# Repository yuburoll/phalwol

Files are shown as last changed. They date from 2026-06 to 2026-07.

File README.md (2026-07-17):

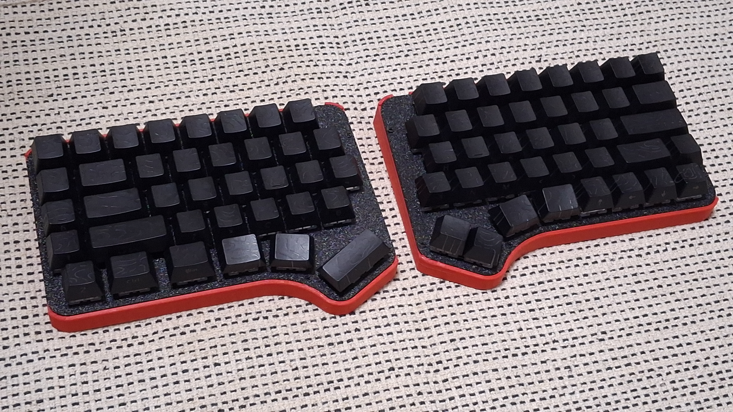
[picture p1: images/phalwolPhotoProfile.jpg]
phalwol


# phalwol
Row staggered 60% keyboard with reversible PCB, inspired by [Hatsukey70](https://scrapbox.io/Hatsukey/)

Hatsuki means August in Japanese, and phalwol means August in Korean. This keyboard layout is an hommage to Hatsukey70, so I want to credit the original design by name.

This keyboard has additional Y/H/B keys which positioned between keyboards, and auxilary row at left outside. You may put the keycaps from numpad.

This keyboard has hotswap-only PCB.

phalwol can change layout to followings:

- Split left shift, to ISO shaped one.(2.25u to 1.25u/1u)

- Split right shift, to HHKB inspired shape.(2.75u to 1.75u/1u)

- Split outside thumb keys(2u to 1u/1u)

- Split backspace(2u to 1u/1u)

- Can use stepped caps lock

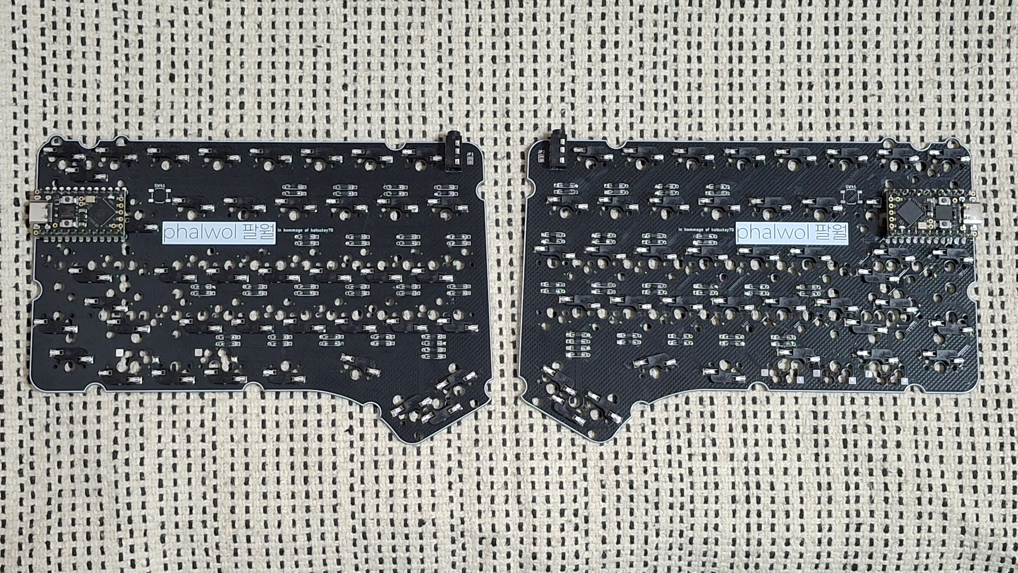
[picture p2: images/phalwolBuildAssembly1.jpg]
phalwolBuildAssembly1


## Preparation

- 2x pro micro form factor dev board

- 2x phalwol PCB Boards, provided from the repo

- 1x printed case sets, 2 parts total, provided from the repo (for thicker case, use "buffed")

- 1x 1.5-1.6T keyboard plate sets, 2 parts total, provided from the repo

- 80x diodes, normally 1N4148

- 84x Kailh hotswap sockets (or compatibles)

- 16x M2x6 screws, flathead

- 2x PJ320A 1/8(3.5mm) TRRS connector (MJ-4PP-9 in other name)

- 2x 4x4x1.5mm surface mount tact switches (optional, for dev boards without reset button)

- 1x 1/8(3.5mm) TRRS cable

- 1-6x PCB Mounted 2u Keyboard Stabilizers, normally 6

- 73-78x MX Keyswitches, normally 73

- 8x 10mm bumpon stickers

- A set of Keycaps, Full-size layout, ANSI preferred.

## Differences between case variations

|Original|Buffed|Frame|
|:---:|:---:|:---:|
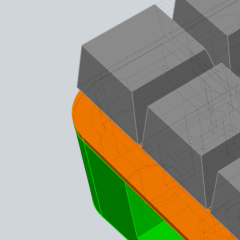
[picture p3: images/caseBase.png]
Base
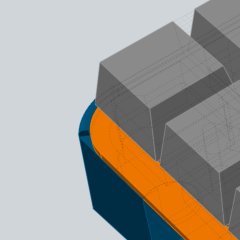
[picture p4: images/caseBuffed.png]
Buff
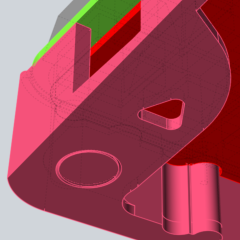
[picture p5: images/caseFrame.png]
Frame
||||

(Frame case are lightest option for 3d print, but it is very brittle)

## Build Guides and Miscellaneous

[phalwol Build Guide](docs/buildGuide.md)

there's some notices before the build:

- You may solder all hotswaps before soldering the dev board.

- Assemble dev board with 2.5mm height pin headers on back side, assume that components side are faced up.

- Jump every jumpers on front side.

[Additional Tenting Stand](https://github.com/yuburoll/yubuGadgets/tree/main/phalilwolTentingStand)

Also take a look at the sibling, [ilwol](https://github.com/yuburoll/ilwol).

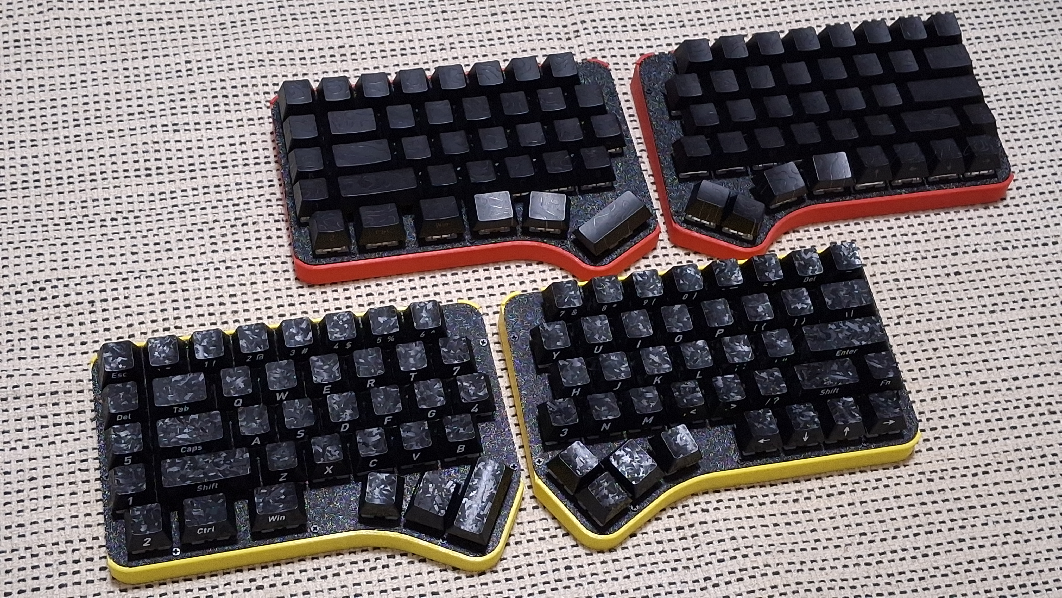
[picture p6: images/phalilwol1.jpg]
phalilwol


## Licenses

All codes are in MIT License.

Markdown documents and photos in docs/images folder are copyrighted, all rights reserved.

The case and layout design of Phalwol is licensed under CC BY-NC-SA 4.0 (Attribution-NonCommercial-ShareAlike) by default, with an additional limited permission for commercial use under the following conditions:

- You are an individual, not acting on behalf of any company or organization.
  
- Your revenue from a single batch of sales does not exceed $2,000.
  
- Your sales are occasional and limited in scope, not ongoing or continuous.

If you want to ask any, please contact the authors.

- me: yuburoll@gmail.com

- Murasaki, the author of original layout Hatsukey70: https://scrapbox.io/Hatsukey/%E4%BD%9C%E8%80%85%E9%80%A3%E7%B5%A1%E5%85%88

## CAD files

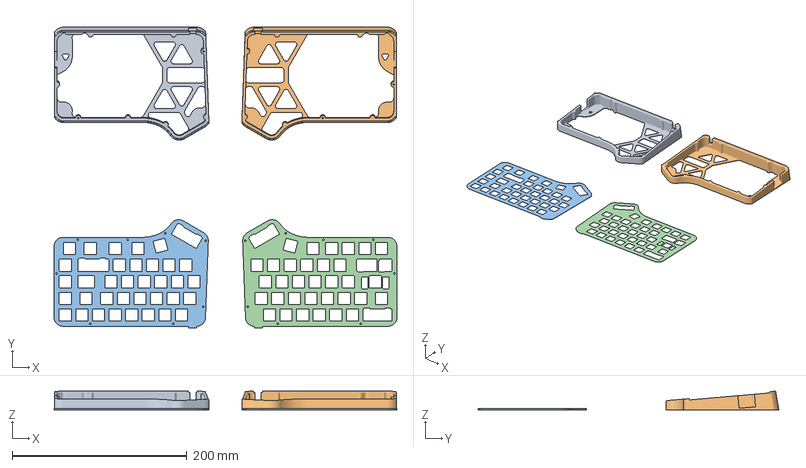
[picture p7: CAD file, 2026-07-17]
case/3mf/phalwolCaseFrame.3mf
392.7 x 344.4 x 21.5 mm
phalwolCaseFrameBridgedL.stl x 2
phalwolPlateBuffedL.stl
phalwolPlateBuffedR.stl

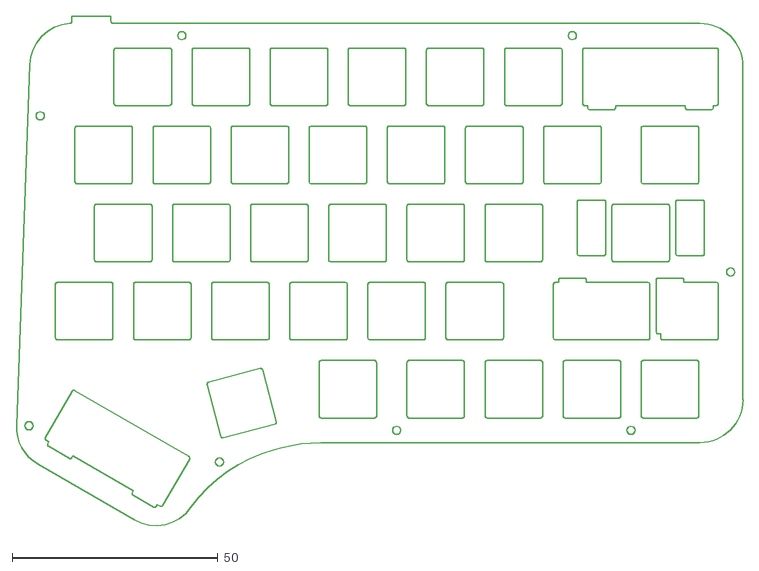
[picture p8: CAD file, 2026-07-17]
case/plateDXF/phalwolPlateBuffedR.dxf
176.8 x 125.2

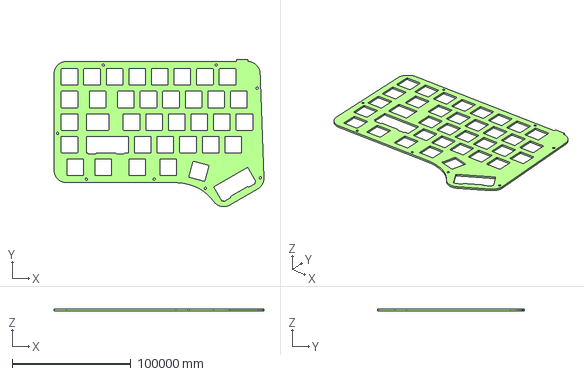
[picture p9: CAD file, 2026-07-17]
case/step/phalwolPlateBuffedL.stp
176699.3 x 123885.5 x 1500.0 mm

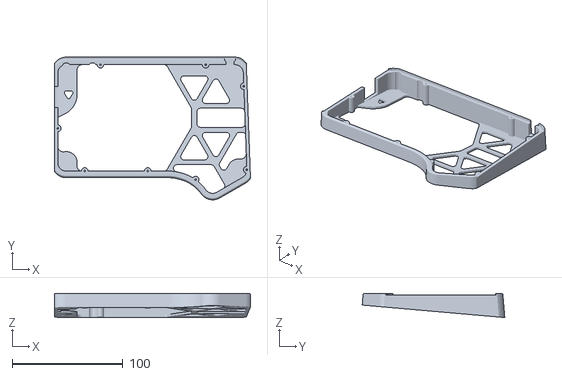
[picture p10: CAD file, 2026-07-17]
case/stl/phalwolCaseFrameBridgedL.stl
177.0 x 128.8 x 21.8

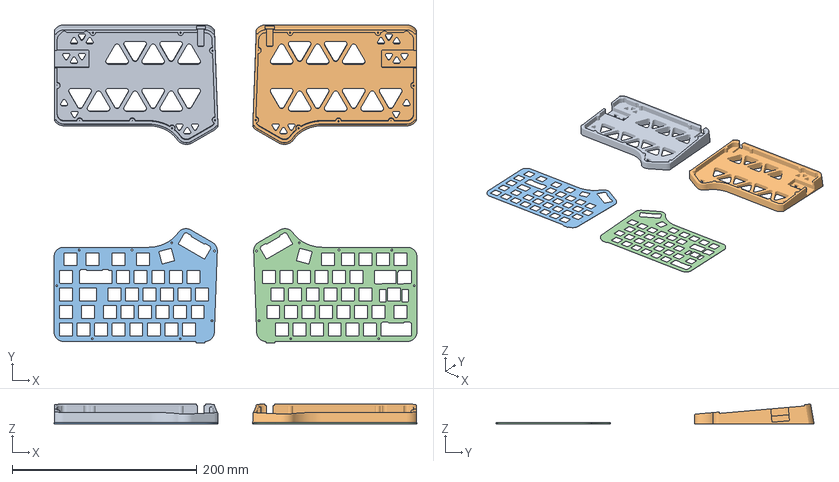
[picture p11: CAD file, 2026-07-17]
case/3mf/phalwolCaseBuffed.3mf
392.7 x 344.4 x 21.5 mm
phalwolCaseBuffedBridgedL.stl x 2
phalwolPlateBuffedL.stl
phalwolPlateBuffedR.stl

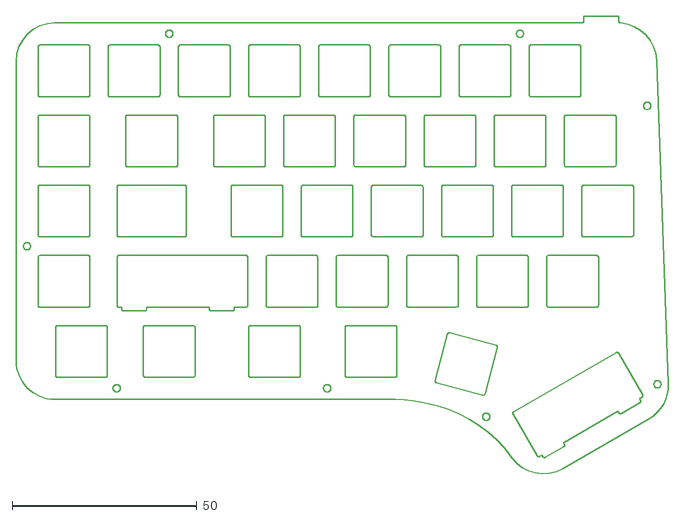
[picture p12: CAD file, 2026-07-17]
case/plateDXF/phalwolPlateBuffedL.dxf
176.8 x 125.2

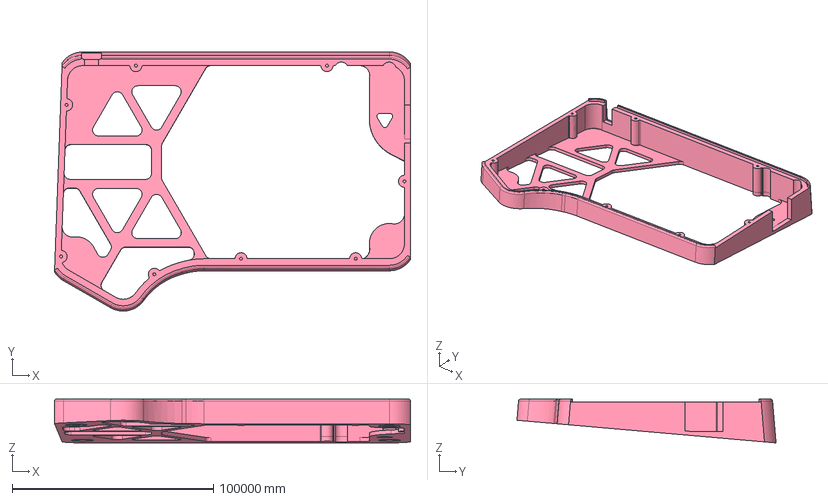
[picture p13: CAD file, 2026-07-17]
case/step/phalwolCaseFrameR.stp
176978.3 x 128826.0 x 21788.3 mm

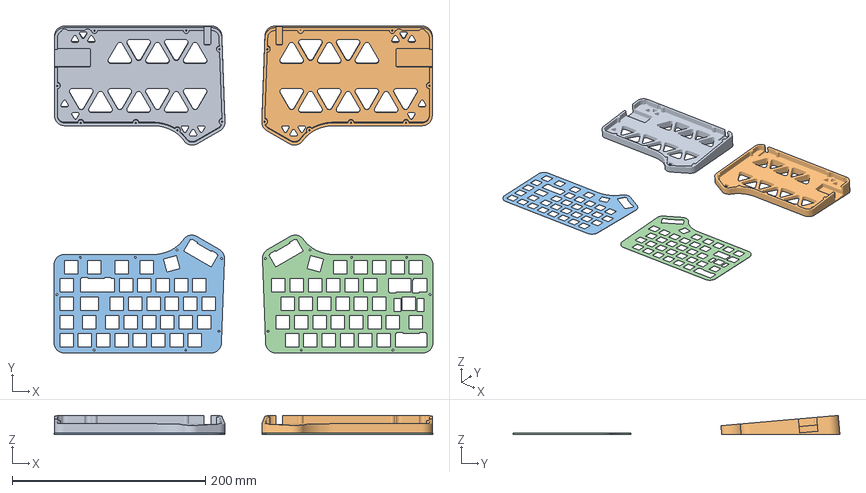
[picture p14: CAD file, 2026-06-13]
case/3mf/phalwolCase.3mf
392.7 x 338.8 x 19.9 mm
phalwolCaseBridgedL.stl x 2
phalwolPlateL.stl
phalwolPlateR.stl

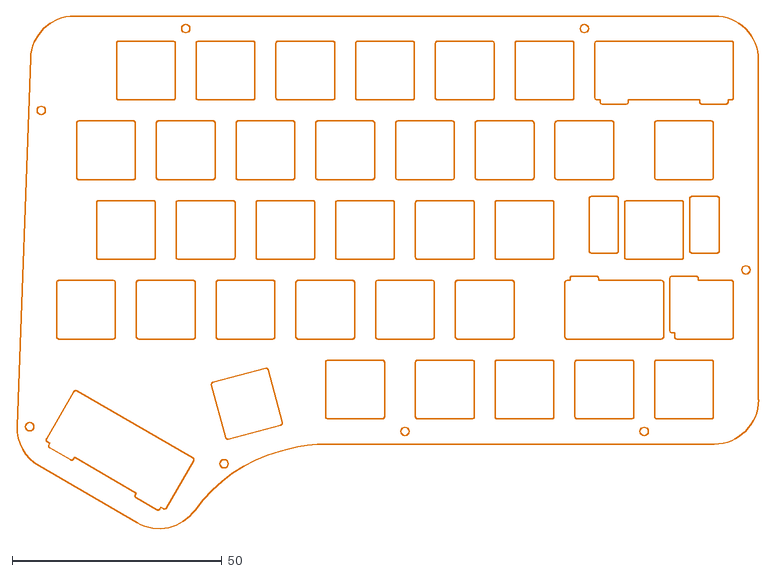
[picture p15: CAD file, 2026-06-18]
case/plateDXF/phalwolPlateR.dxf
176.8 x 123.4

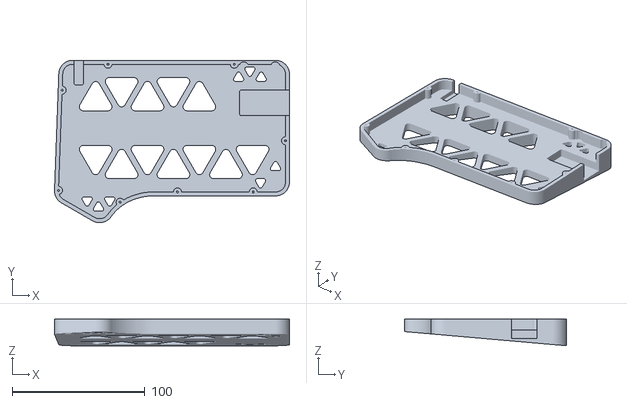
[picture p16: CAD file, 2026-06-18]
case/stl/phalwolCaseBridgedR.stl
176.7 x 122.1 x 20.0

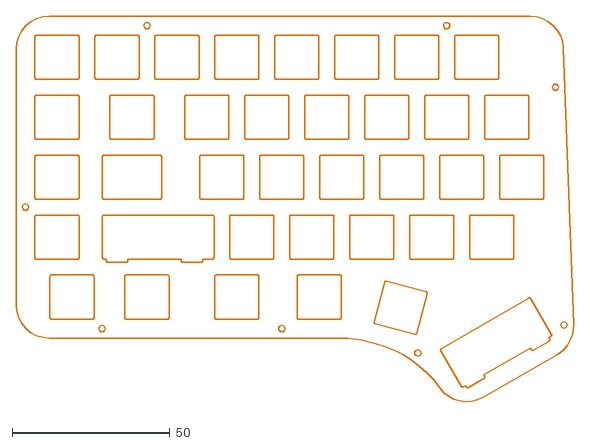
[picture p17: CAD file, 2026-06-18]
case/plateDXF/phalwolPlateL.dxf
176.8 x 123.4

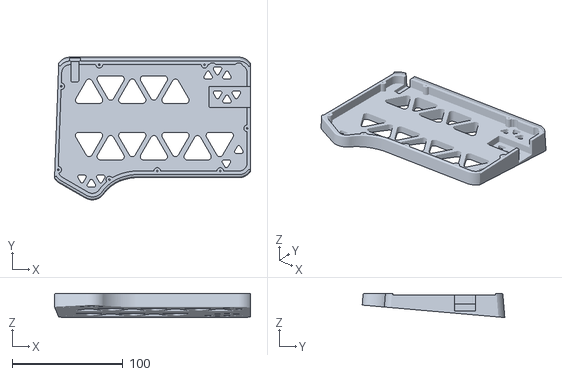
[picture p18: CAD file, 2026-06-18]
case/stl/phalwolCaseBuffedBridgedR.stl
177.0 x 128.8 x 21.8

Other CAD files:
case/stl/phalwolCaseFrameBridgedR.stl
case/step/phalwolPlateBuffedR.stp
case/step/phalwolCaseFrameL.stp
case/step/phalwolPlateR.stp
case/stl/phalwolCaseBridgedL.stl
case/step/phalwolPlateL.stp
case/raw/phalwol.3dm
case/step/phalwolCaseBuffedL.stp
case/step/phalwolCaseBuffedR.stp
case/step/phalwolCaseL.stp
case/step/phalwolCaseR.stp
case/stl/phalwolCaseBuffedBridgedL.stl
case/stl/phalwolCaseBuffedL.stl
case/stl/phalwolCaseBuffedR.stl
case/stl/phalwolCaseFrameL.stl
case/stl/phalwolCaseFrameR.stl
case/stl/phalwolCaseL.stl
case/stl/phalwolCaseR.stl
case/stl/phalwolPlateBuffedL.stl
case/stl/phalwolPlateBuffedR.stl
case/stl/phalwolPlateL.stl
case/stl/phalwolPlateR.stl

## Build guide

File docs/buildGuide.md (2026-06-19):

# Build Guide
this is build guide for phalwol.

the build guide contains photo of prototype version. newest version have following differences:

- the corner screws of outside top are moved 1u inside, so do the PCB design.

- lower pinky modifier keys are not changeable. as black marked in prototype PCB

This documents are translated by generative AI, so there can be some misleading texts.

### Additional Resources
[**Soldering Tips**](solderingTip.md)

# PCB Preparation
Prepare two PCBs for the phalwol. Since these are reversible PCBs, be careful to place components on different sides for each board.

The side where components will be placed is treated as the back, and the side without components is treated as the front. **All components go on back side only, so please be careful when soldering.**

# Soldering the Diodes
Solder the diodes. The photos show SMD diodes being used, but THT diodes can also be used.

In the photo, the hot-swap sockets are soldered first, but I recommend soldering the diodes first.

When using SMD diodes, first apply a solder blob to one side of the pad with a soldering iron, as shown in the following photos.

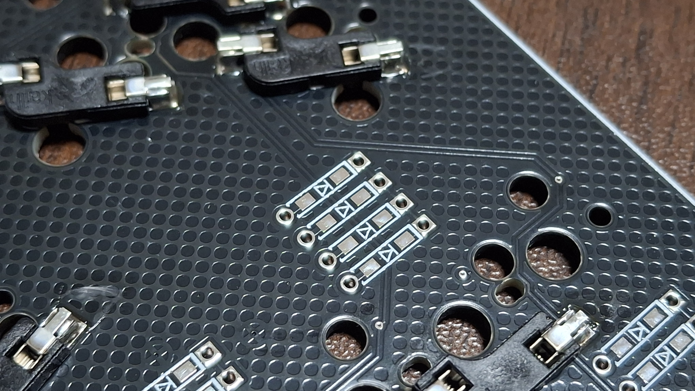
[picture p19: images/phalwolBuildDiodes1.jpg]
phalwolBuildDiodes1

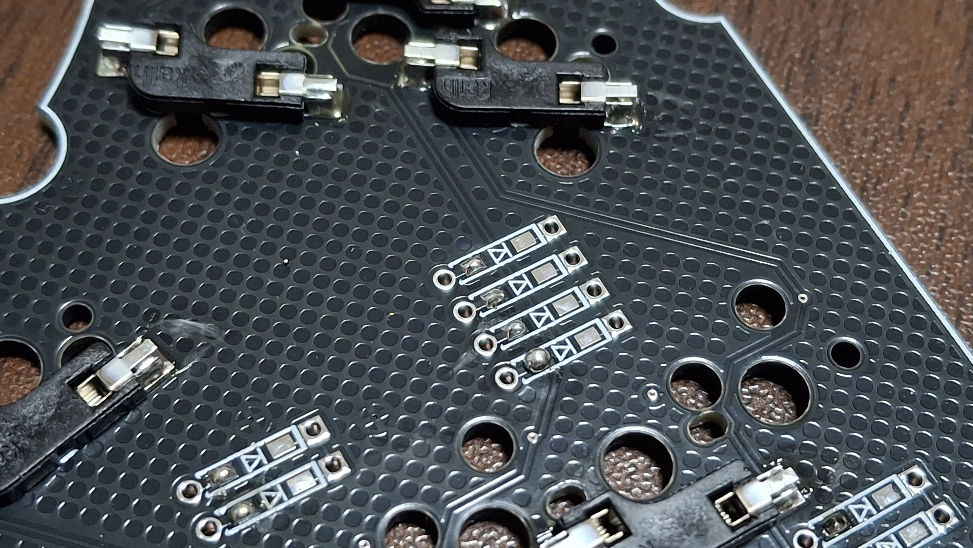
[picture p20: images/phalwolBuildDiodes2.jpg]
phalwolBuildDiode2


Reheat the solder blob with the iron to melt it, align the diode in the correct orientation and place it in position, then remove the iron.

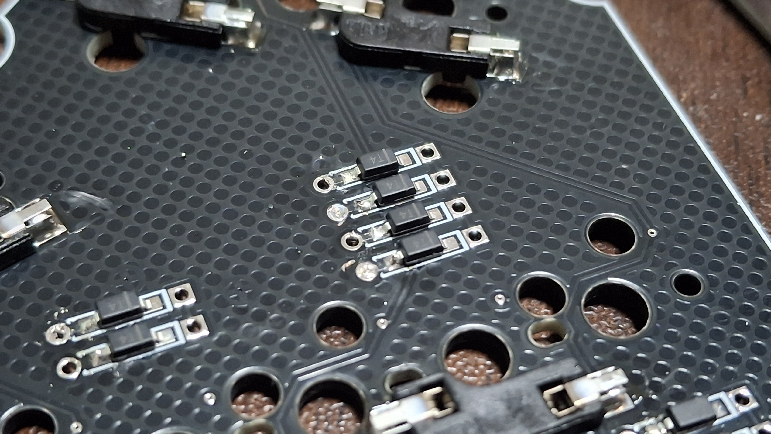
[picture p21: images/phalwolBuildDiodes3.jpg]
phalwolBuildDiode3


Once it is seated properly, solder the opposite leg.

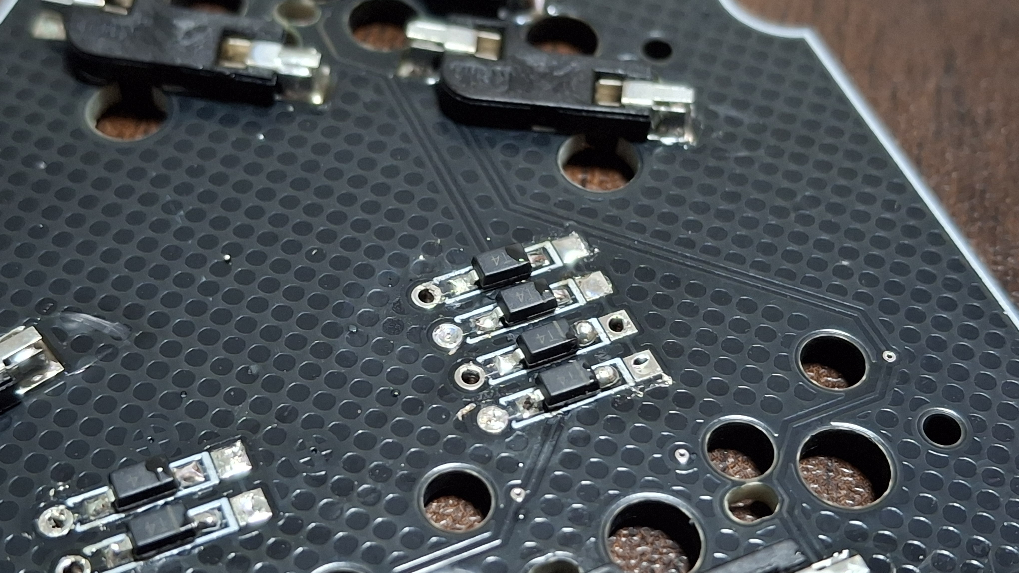
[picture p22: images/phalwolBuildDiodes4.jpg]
phalwolBuildDiode4


# Soldering the Hot-swap Sockets
Solder the hot-swap sockets. The process is largely the same as soldering the diodes and LEDs.

As before, apply a solder blob to one side of the pad, reheat the blob to melt it, place the component and hold it in position, remove the iron, then solder the opposite leg.

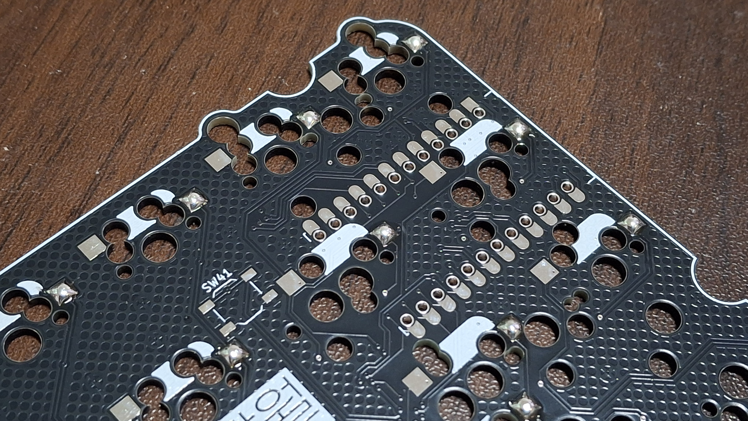
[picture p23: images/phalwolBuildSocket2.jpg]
phalwolBuildSocket2

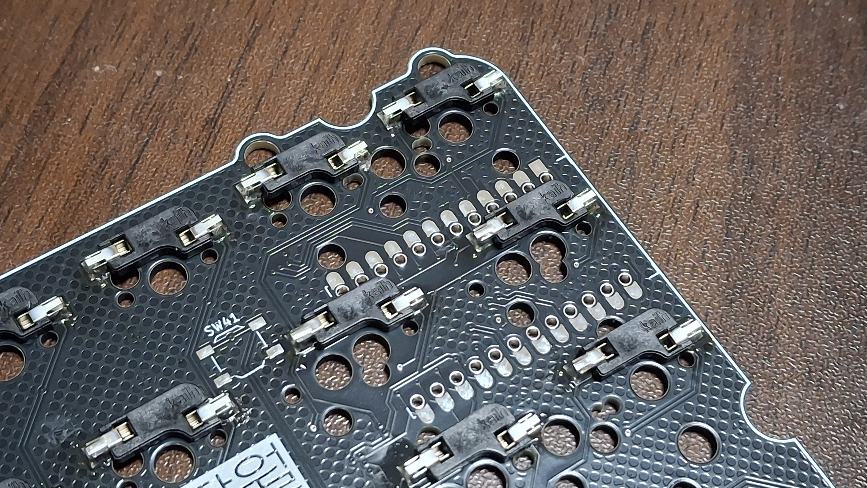
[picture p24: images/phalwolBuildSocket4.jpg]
phalwolBuildSocket4


# Soldering the TRRS Jack and the Jumper
Refer to the following photos to identify where the TRRS jack will be placed. The jack will be placed on back side, so you may solder that on front side.

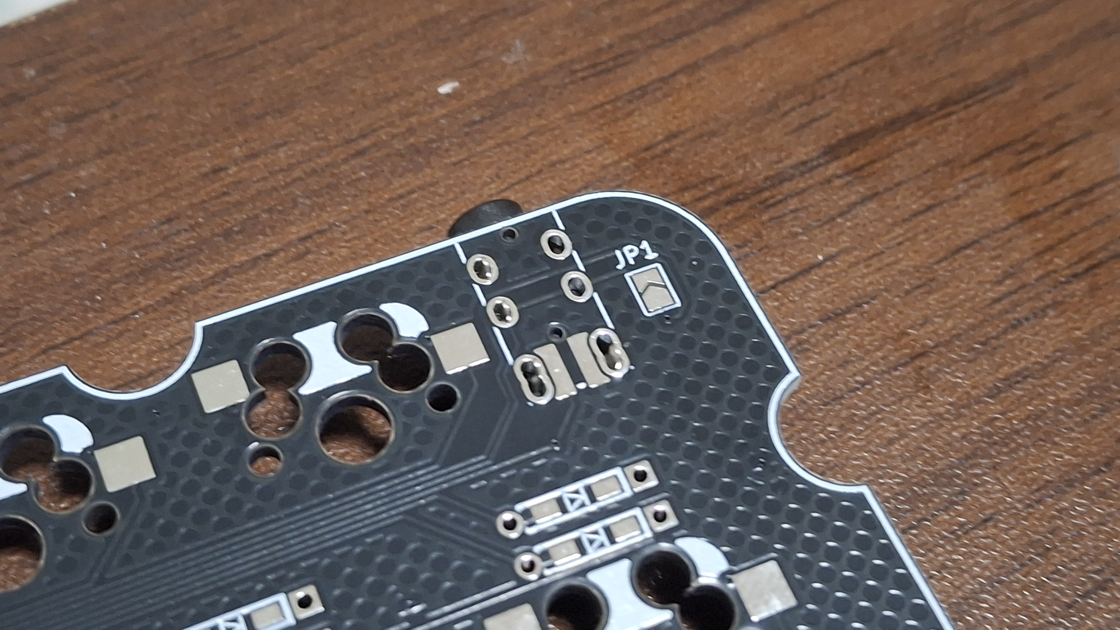
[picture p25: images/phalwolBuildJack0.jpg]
phalwolBuildJack0


Solder the TRRS jack. When soldering the Tip and Sleeve pins, also bridge them to the adjacent pads as shown in the photo.

And, On the front side seen when soldering the jack, bridge the jumpers located aside. Apply enough solder so that a blob forms on top.

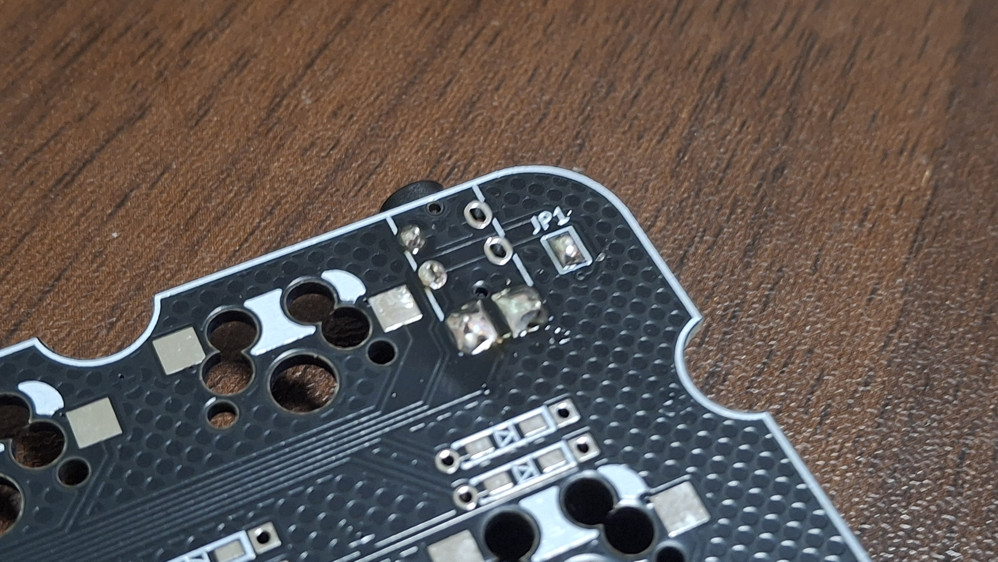
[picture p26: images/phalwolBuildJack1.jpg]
phalwolBuildJack1


# Soldering the Dev Board
First, check the header pins on the provided Pro Micro dev board. The outermost row of header pins past 5V is not needed, so trim them off.

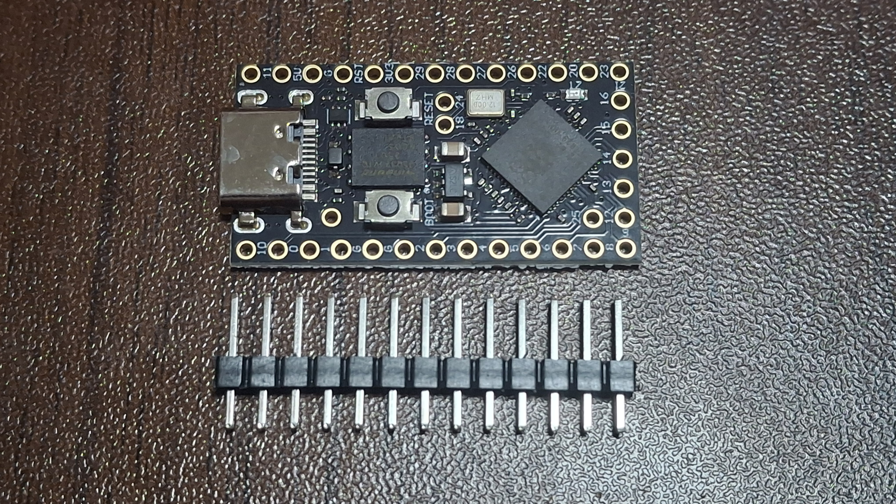
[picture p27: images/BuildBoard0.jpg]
BuildBoard0

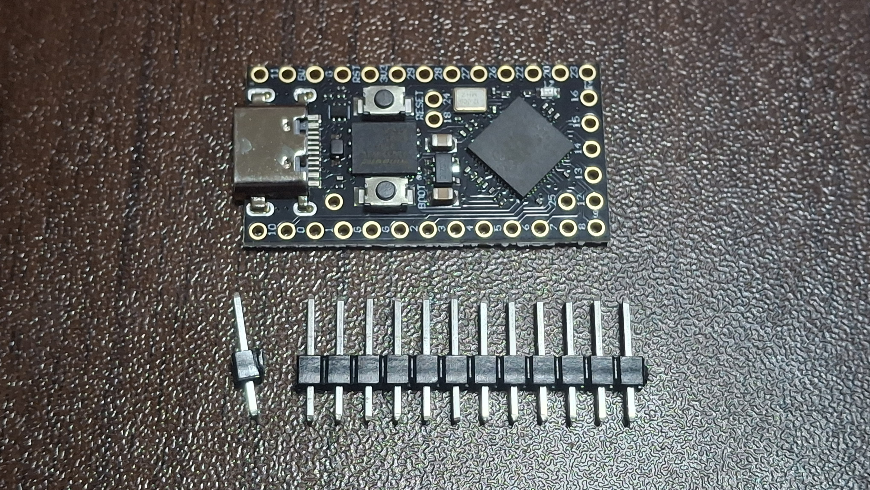
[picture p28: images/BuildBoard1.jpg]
BuildBoard1


Insert the header pins starting from 5V, align them, and solder the dev board. When soldering, make sure the components face upward as shown in the photo.

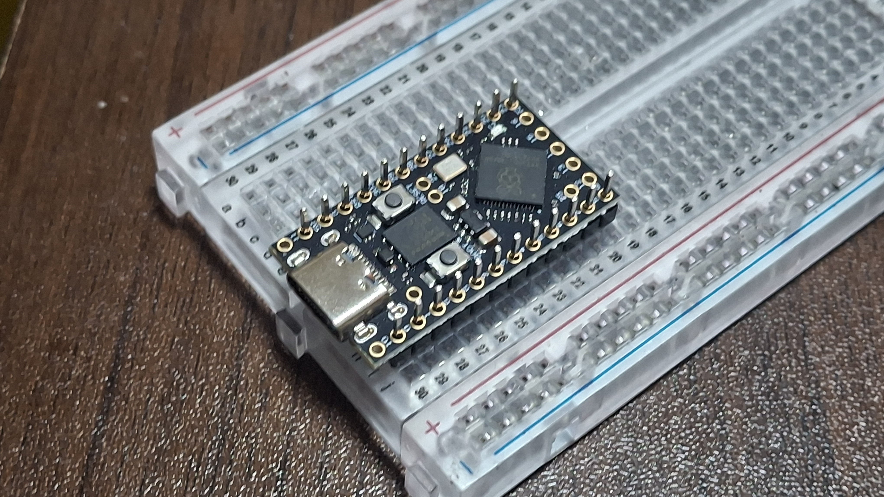
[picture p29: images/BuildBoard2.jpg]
BuildBoard2

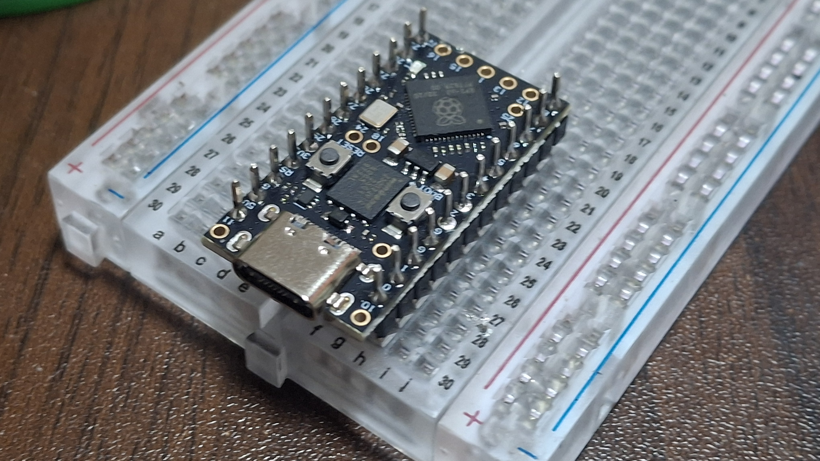
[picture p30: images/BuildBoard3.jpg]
BuildBoard3


Place the dev board with the soldered header pins on top of the already-soldered hot-swap sockets. Press down firmly to ensure a tight fit.

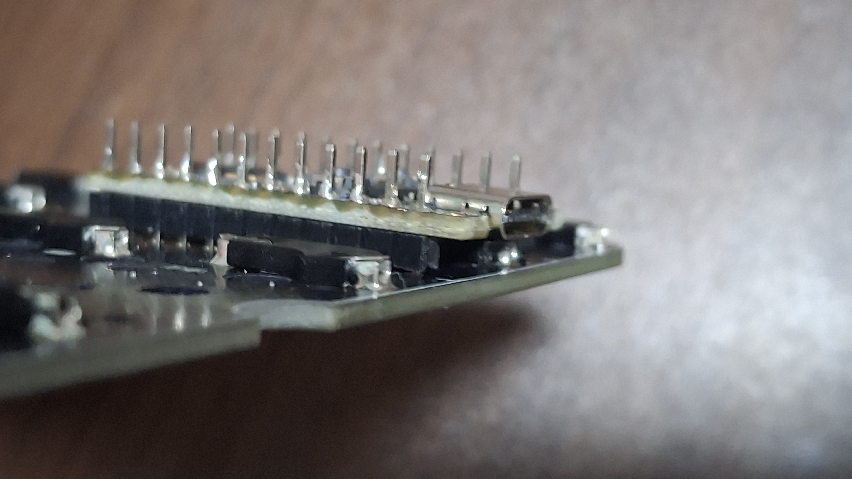
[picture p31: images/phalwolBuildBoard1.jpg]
phalwolBuildBoard1

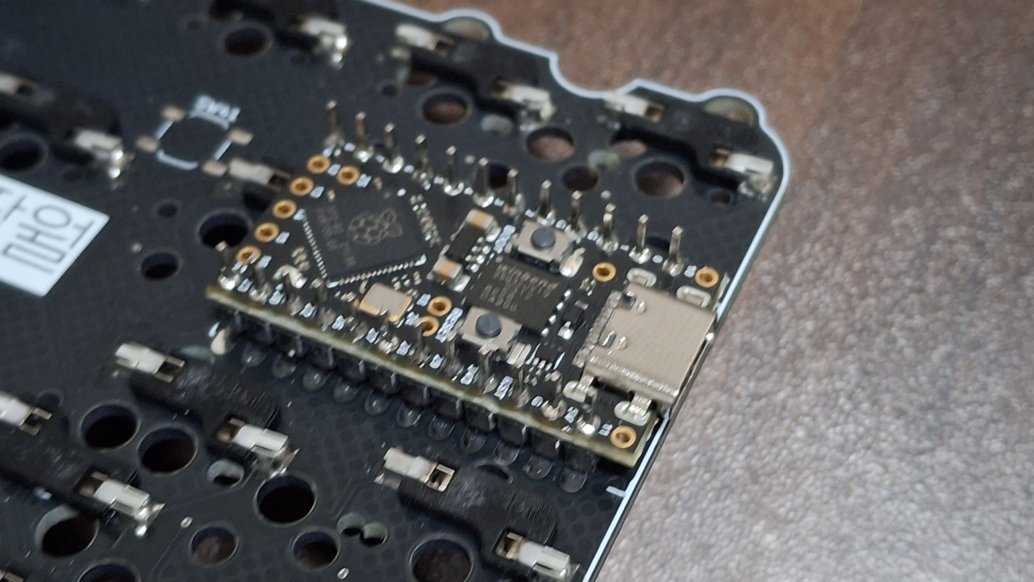
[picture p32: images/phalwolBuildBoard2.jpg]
phalwolBuildBoard2

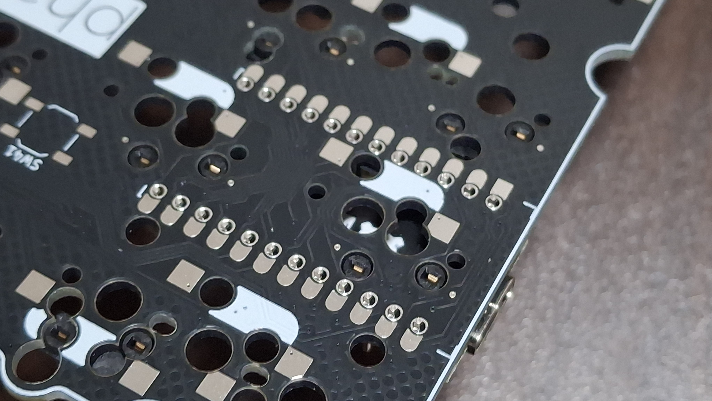
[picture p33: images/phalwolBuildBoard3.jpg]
phalwolBuildBoard3


Just like when soldering the TRRS jack pins, bridge the header pins to the adjacent pads as if soldering jumpers. Since a large amount of solder is used, there is a risk of bridging with flux, so be sure to clean the area with alcohol after soldering.

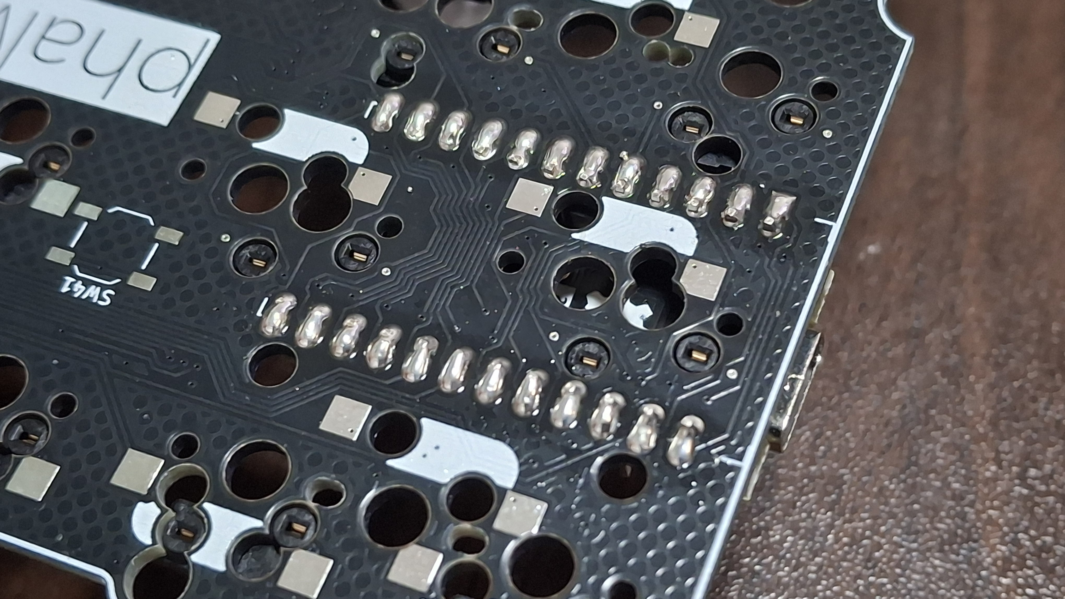
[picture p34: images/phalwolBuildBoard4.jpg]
phalwolBuildBoard4


# Check PCB and flash firmware before Assembly
The finished PCBs look like following images.

phalwolBuildAssembly1
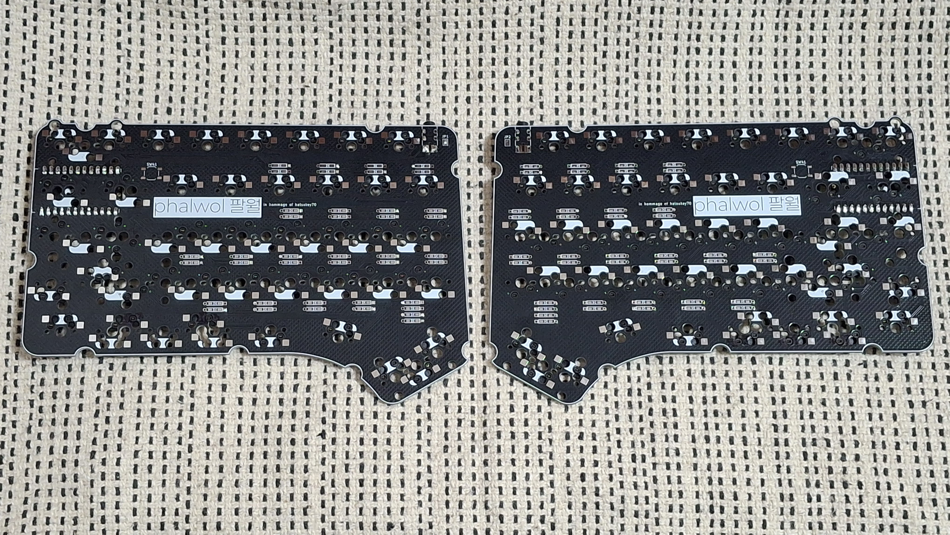
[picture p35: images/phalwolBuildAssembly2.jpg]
phalwolBuildAssembly2


If you're a keyboard enthusiast, I'd recommend installing stabilizers at keycap positions 2u or larger, as shown in the following photo.

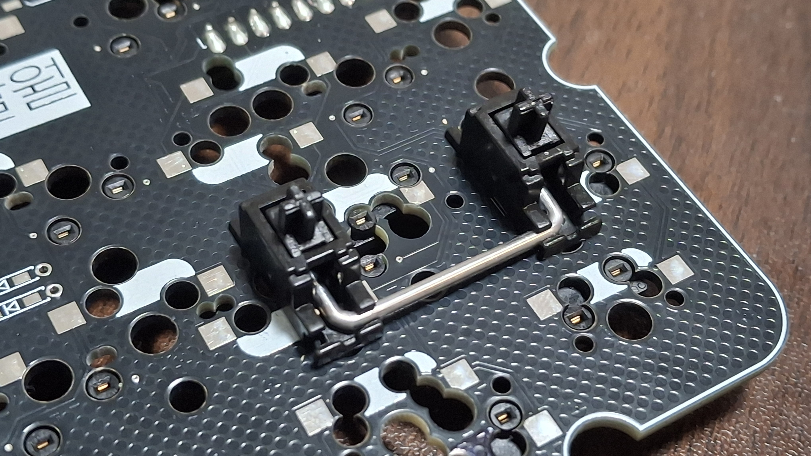
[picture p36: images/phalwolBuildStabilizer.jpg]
phalwolBuildStabilizer


Also, please flash the firmware before assembling the case.

For the RP2040 promicro, hold down the Boot button on the development board while connecting the USB, then drop the .uf2 file onto the removable disk that appears.

For the ATmega32U4 promicro, load the firmware .hex in your flashing tool (e.g., QMK Toolbox). Then, with the USB connected, briefly short RST and GND with a conductor, or solder a 4x4x1.5mm tactile switch to those pads and press it. The Caterina bootloader will activate and the tool will flash the firmware.

# Assembly
First, assemble plate and switches together with proper direction, and assemble PCB on it.

You can fasten all the switches to the plate first and then join it to the PCB, but I also recommend the method shown in the photo: attach the switches to the four corners first, place the PCB, and then assemble the remaining switches one by one.

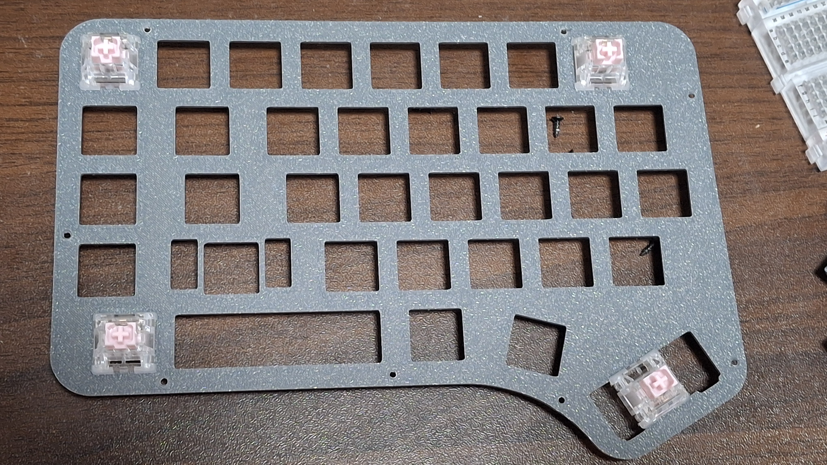
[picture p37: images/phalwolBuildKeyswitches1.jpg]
phalwolBuildKeyswitches1

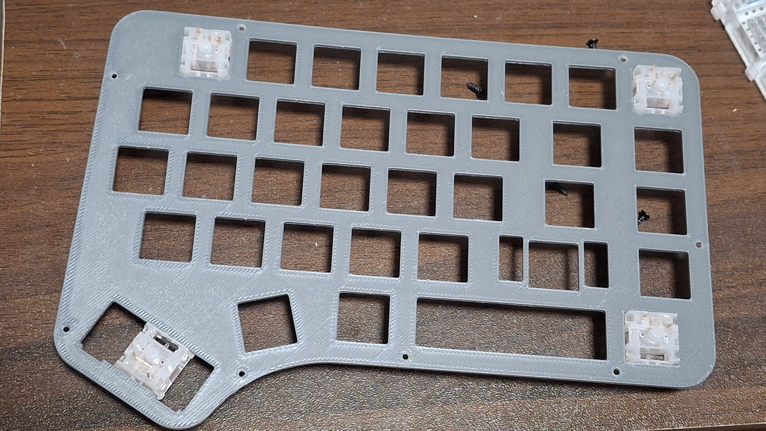
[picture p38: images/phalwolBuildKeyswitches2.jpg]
phalwolBuildKeyswitches2

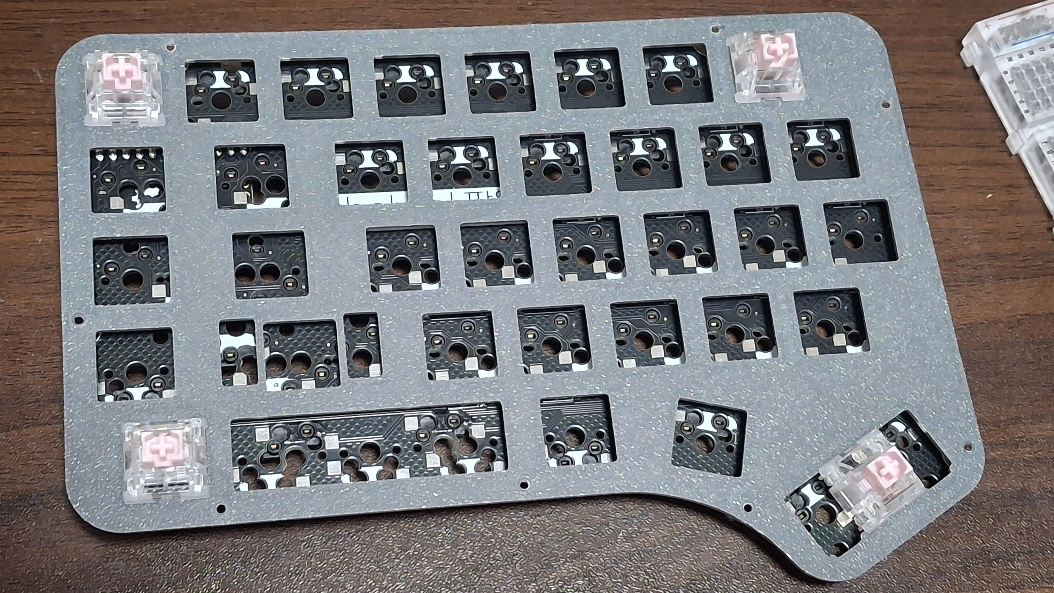
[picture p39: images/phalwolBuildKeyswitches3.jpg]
phalwolBuildKeyswitches3

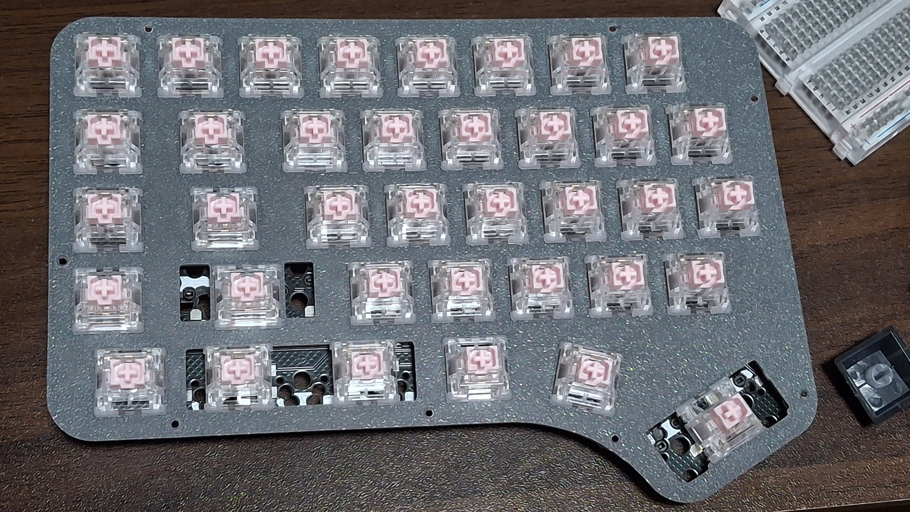
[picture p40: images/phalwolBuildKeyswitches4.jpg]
phalwolBuildKeyswitches4


Place the plate assembly over the case and fasten it with screws at eight points per side to complete the build. also, you may add four bumpons on the bottom of the case.

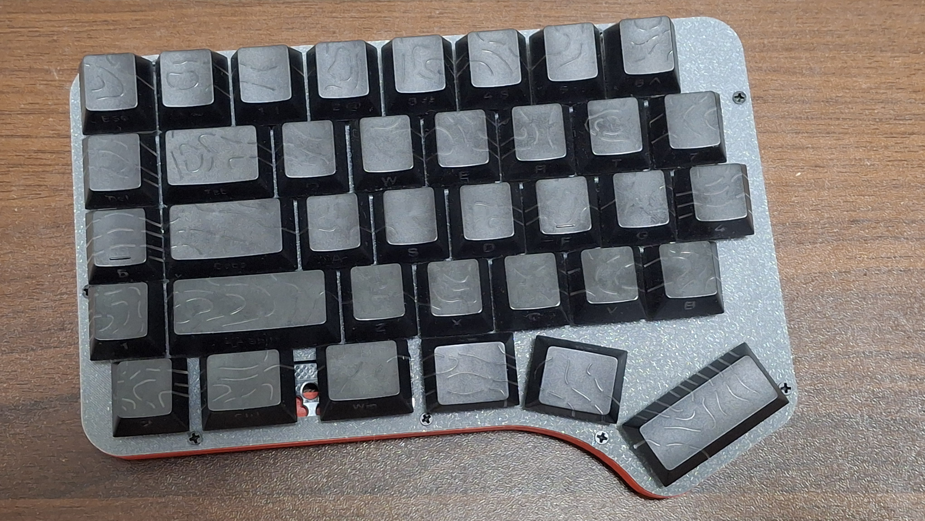
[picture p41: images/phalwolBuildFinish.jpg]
phalwolBuildFinish


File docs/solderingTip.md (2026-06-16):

# Soldering Tips

A collection of soldering advice and tips.

This documents are translated by generative AI, so there can be some misleading texts.

## Supplies

- Soldering iron & stand: A chisel tip is the most convenient to work with. I recommend getting one that can maintain a temperature of at least 400–500°C.

- Solder: Choose between leaded and lead-free solder. Leaded solder is less stressful to work with, but it is not good for your health.

- Solder paste (flux): **The god of soldering.** If your solder joints are not turning out well, frequently wipe and coat the iron tip with paste flux.

- Damp sponge/paper towel, or a tip cleaner (brass wool): Used to wipe residual solder off the iron tip.

- Solder wick or solder sucker: Used to fix bad solder joints. For beginners, solder wick is recommended.

- Flush cutters: Used to clip the legs of THT diodes after soldering.

## Ventilate Your Workspace

The metal fumes from melting solder are a concern, but they are actually quite minimal. The bigger issue is the smoke from the rosin flux inside the solder burning and melting — it is quite harmful and produces a lot of smoke. It is very bad for your health, so ventilate the area, or if ventilation is not possible, make sure to use an air purifier. Always wear a mask.

## Double-Check Before Soldering Components

It is easier to prevent a bad solder joint than to fix one. To correct a solder joint, apply flux to solder wick and press it against the joint with the iron, or apply a small amount of flux to the iron tip, melt the solder, and simultaneously press a solder sucker against it to absorb the solder.

## Apply Flux If Solder Is Not Sticking

Melt flux onto the iron tip to coat it, or use a flux pen to apply it directly to the PCB pads.

## Touch the Iron First When Starting, Remove It Last When Finishing

Place the iron on the pad first to preheat the PCB and component, then melt the solder onto the joint. When finishing, remove the solder first, then remove the iron last.

## Use Masking Tape to Temporarily Hold Components

For components like sockets, securing them with masking tape before soldering is helpful. This is especially important when you need to flip the board over, as components can be difficult to hold in place.

## Clean the Flux After Soldering

Scrub the remaining flux and any areas prone to short circuits thoroughly using a toothbrush dipped in isopropyl alcohol. You can also spray alcohol on the board, scrub with a toothbrush, and let it dry. Keyboard key inputs may work fine with residual flux, but encoders and analog inputs are more susceptible to issues caused by flux bridging.

## If Something Goes Wrong, Reflow and Clean

Problems can arise from cold joints, insufficient solder, excess solder bridging neighboring pads, or electrical interference from flux residue. In most cases, reflowing the solder joint and cleaning the flux will resolve the issue.

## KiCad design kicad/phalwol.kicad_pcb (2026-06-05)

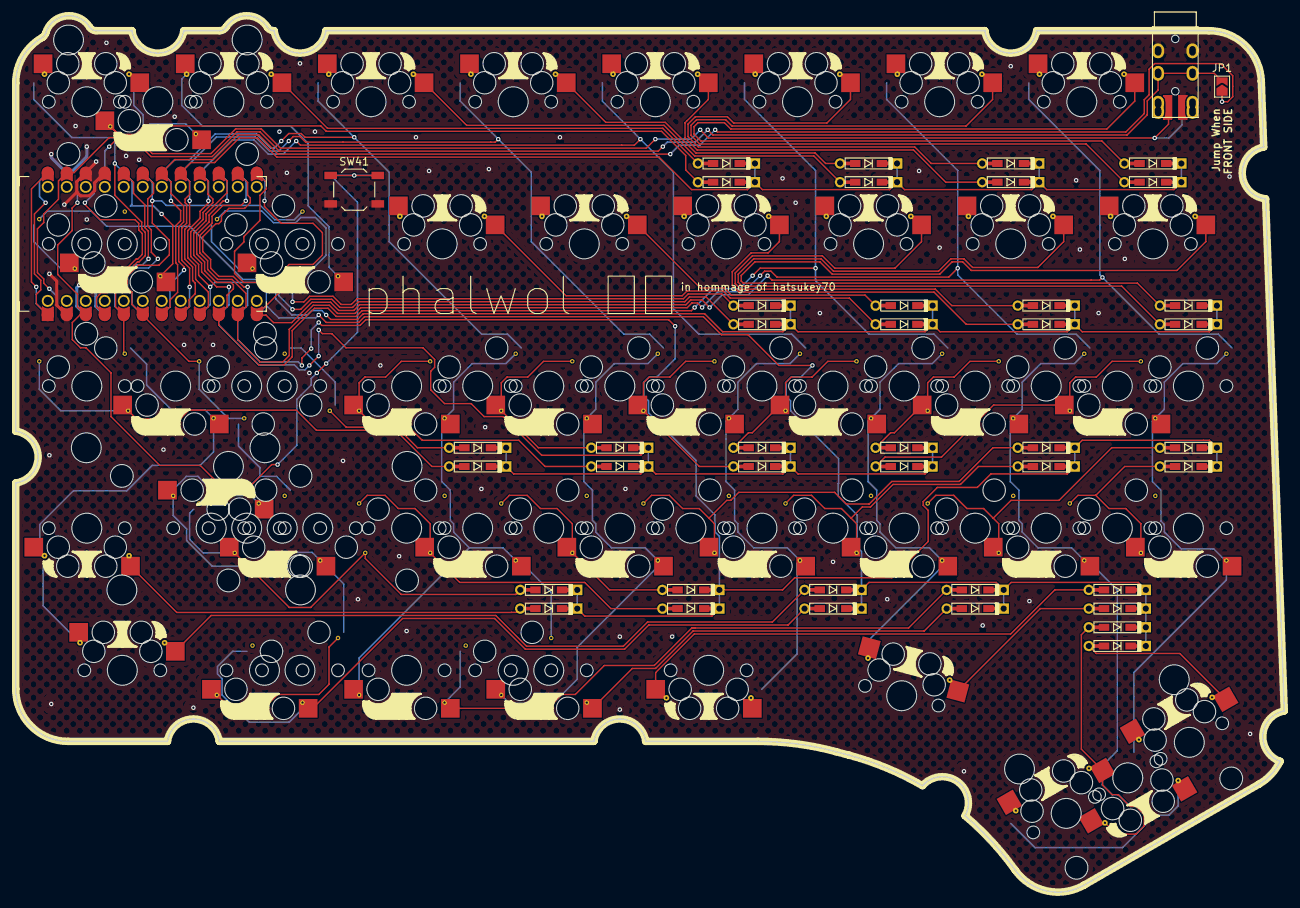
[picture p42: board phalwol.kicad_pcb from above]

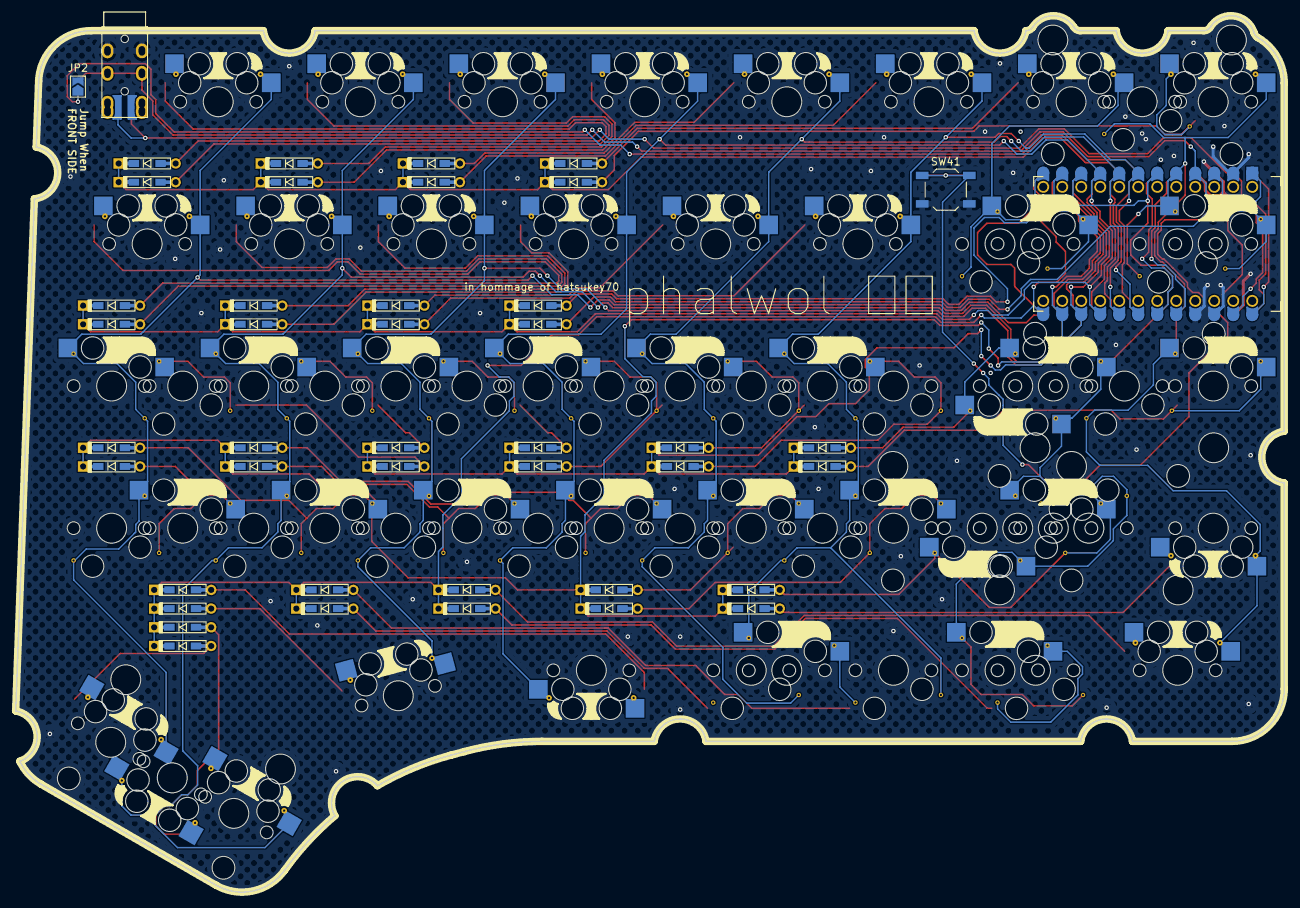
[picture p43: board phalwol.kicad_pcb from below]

Board: 2 copper layers, 169.6 x 117.1 mm, 108 parts (23 on the bottom side), 58 nets.

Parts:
D1, D2, D3, D4, D5, D6, D7, D8, D9, D10, D11, D12, D13, D14, D15, D16, D17, D18, D19, D20, D21, D22, D23, D24, D25, D26, D27, D28, D29, D30, D31, D32, D33, D34, D35, D36, D37, D38, D39, D40: D; Diode_TH_SMD_REVERSIBLE
J1: AudioJack4; TRRS-PJ-320A-ReversiblePad
JP1, JP2: SolderJumper_2_Open; SolderJumper-2_P1.3mm_Open_TrianglePad1.0x1.5mm
SW1, SW9, SW9#2, SW10, SW10#2, SW17, SW17#2, SW18, SW19, SW19#2, SW20, SW20#2, SW21, SW21#2, SW22, SW22#2, SW23, SW23#2, SW24, SW24#2, SW26, SW26#2, SW26#3, SW26#4, SW27, SW27#2, SW28, SW28#2, SW29, SW29#2, SW30, SW30#2, SW31, SW31#2, SW32, SW32#2, SW34, SW34#2, SW35, SW35#2, SW36: SW_Push; MX_HotswapOneside_Via_Guided
SW1#2, SW2, SW3, SW4, SW5, SW6, SW7, SW8, SW11, SW12, SW13, SW14, SW15, SW16, SW25, SW33, SW37, SW38, SW39, SW39#2, SW40: SW_Push; MX_Hotswap_FootprintPropertyFix_Guided
SW41, SW41#2: SW_Push; SW_SPST_TL3342
U1: ProMicro; ProMicro_ReveribleThru_ComponentUp_OuterPad

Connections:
COL1: SW1.1, SW1#2.1, SW9.1, SW9#2.1, SW17.1, SW17#2.1, SW25.1, SW33.1, U1.20 (F4/A3)
COL2: SW2.1, SW10.1, SW10#2.1, SW18.1, SW26.1, SW26#2.1, SW26#3.1, SW26#4.1, SW34.2, SW34#2.1, U1.19 (F5/A2)
COL3: SW3.1, SW11.1, SW19.1, SW19#2.1, SW27.1, SW27#2.1, SW35.2, SW35#2.1, U1.18 (F6/A1)
COL4: SW4.1, SW12.1, SW20.1, SW20#2.1, SW28.1, SW28#2.1, SW36.2, U1.17 (F7/A0)
COL5: SW5.1, SW13.1, SW21.1, SW21#2.1, SW29.1, SW29#2.1, SW37.1, U1.16 (B1/15)
COL6: SW6.1, SW14.1, SW22.1, SW22#2.1, SW30.1, SW30#2.1, SW38.1, U1.15 (B3/14)
COL7: SW7.1, SW15.1, SW23.1, SW23#2.1, SW31.1, SW31#2.1, SW39.1, SW39#2.1, U1.14 (B2/16)
COL8: SW8.1, SW16.1, SW24.1, SW24#2.1, SW32.1, SW32#2.1, SW40.1, U1.13 (B6/10)
GND: J1.R2, J1.S, JP2.2 (B), SW41.2, SW41#2.2, U1.3 (GND), U1.4 (GND), U1.23 (GND)
HAND: JP1.1 (A), JP2.1 (A), U1.7 (4/D4)
unnamed: D1.2 (A), SW1.2, SW1#2.2
unnamed: D2.2 (A), SW2.2
unnamed: D3.2 (A), SW3.2
unnamed: D4.2 (A), SW4.2
unnamed: D5.2 (A), SW5.2
unnamed: D6.2 (A), SW6.2
unnamed: D7.2 (A), SW7.2
unnamed: D8.2 (A), SW8.2
unnamed: D9.2 (A), SW9.2, SW9#2.2
unnamed: D10.2 (A), SW10.2, SW10#2.2
unnamed: D11.2 (A), SW11.2
unnamed: D12.2 (A), SW12.2
unnamed: D13.2 (A), SW13.2
unnamed: D14.2 (A), SW14.2
unnamed: D15.2 (A), SW15.2
unnamed: D16.2 (A), SW16.2
unnamed: D17.2 (A), SW17.2, SW17#2.2
unnamed: D18.2 (A), SW18.2
unnamed: D19.2 (A), SW19.2, SW19#2.2
unnamed: D20.2 (A), SW20.2, SW20#2.2
unnamed: D21.2 (A), SW21.2, SW21#2.2
unnamed: D22.2 (A), SW22.2, SW22#2.2
unnamed: D23.2 (A), SW23.2, SW23#2.2
unnamed: D24.2 (A), SW24.2, SW24#2.2
unnamed: D25.2 (A), SW25.2
unnamed: D26.2 (A), SW26.2, SW26#2.2, SW26#3.2, SW26#4.2
unnamed: D27.2 (A), SW27.2, SW27#2.2
unnamed: D28.2 (A), SW28.2, SW28#2.2
unnamed: D29.2 (A), SW29.2, SW29#2.2
unnamed: D30.2 (A), SW30.2, SW30#2.2
unnamed: D31.2 (A), SW31.2, SW31#2.2
unnamed: D32.2 (A), SW32.2, SW32#2.2
unnamed: D33.2 (A), SW33.2
unnamed: D34.2 (A), SW34.1, SW34#2.2
unnamed: D35.2 (A), SW35.1, SW35#2.2
unnamed: D36.2 (A), SW36.1
unnamed: D37.2 (A), SW37.2
unnamed: D38.2 (A), SW38.2
unnamed: D39.2 (A), SW39.2, SW39#2.2
unnamed: D40.2 (A), SW40.2
ROW1: D1.1 (K), D2.1 (K), D3.1 (K), D4.1 (K), D5.1 (K), D6.1 (K), D7.1 (K), D8.1 (K), U1.8 (5/C6)
ROW2: D9.1 (K), D10.1 (K), D11.1 (K), D12.1 (K), D13.1 (K), D14.1 (K), D15.1 (K), D16.1 (K), U1.9 (6/D7)
ROW3: D17.1 (K), D18.1 (K), D19.1 (K), D20.1 (K), D21.1 (K), D22.1 (K), D23.1 (K), D24.1 (K), U1.10 (7/E6)
ROW4: D25.1 (K), D26.1 (K), D27.1 (K), D28.1 (K), D29.1 (K), D30.1 (K), D31.1 (K), D32.1 (K), U1.11 (8/B4)
ROW5: D33.1 (K), D34.1 (K), D35.1 (K), D36.1 (K), D37.1 (K), D38.1 (K), D39.1 (K), D40.1 (K), U1.12 (9/B5)
RST: SW41.1, SW41#2.1, U1.22 (RST)
SERIAL: J1.T, U1.2 (RX1/D2)
VCC: J1.R1, JP1.2 (B), U1.21 (VCC)

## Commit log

2026-05-16 phalwol kicad upload
    [phalwol.kicad_pcb, phalwol.kicad_sch]
2026-05-16 update pcb and schema
    [phalwol.kicad_pcb, phalwol.kicad_sch]
2026-05-16 connect schema and pcb
    [phalwol.kicad_pcb, phalwol.kicad_sch]
2026-05-17 update pcb
    [phalwol.kicad_pcb]
2026-05-19 finished wiring
    [phalwol.kicad_pcb]
2026-05-19 hotfix wiring
    [phalwol.kicad_pcb, phalwol.kicad_sch]
2026-05-21 fix proper hole position
    [phalwol.3dm]
2026-05-22 add phalwol board art
    [phalwol.kicad_pcb]
2026-05-22 polish pcb
    [phalwol.kicad_pcb]
2026-05-29 create gerber
    [phalwol-B_Cu.gbr, phalwol-B_Mask.gbr, phalwol-B_Paste.gbr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]
2026-06-02 change modifier cluster to fixed one
    [phalwol.kicad_pcb]
2026-06-05 gerber update
    [phalwol-B_Cu.gbr, phalwol-B_Mask.gbr, phalwol-B_Paste.gbr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]
2026-06-05 edit hole size for jack
    [phalwol-B_Cu.gbr, phalwol-B_Mask.gbr, phalwol-B_Paste.gbr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]
2026-06-05 edit case for stabilizer collide
    [phalwol.3dm]
2026-06-05 minor hole changement
    [phalwol.3dm]
2026-06-05 edit pcb for proper design'
    [phalwol-B_Cu.gbr, phalwol-B_Mask.gbr, phalwol-B_Paste.gbr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]
2026-06-11 change hole offset
    [phalwol.3dm]
2026-06-13 case upload
    [phalwolCase.3mf, phalwolCaseBridgedL.stl, phalwolCaseBridgedR.stl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]
2026-06-13 add buffcase for phalwol
    [phalwol.3dm, phalwolCaseBuffedBridgedL.stl, phalwolCaseBuffedBridgedR.stl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]
2026-06-13 add 3mf and fix non-manifold geo
    [phalwol.3dm, phalwolCaseBuffed.3mf, phalwolCaseBuffedBridgedL.stl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]
2026-06-18 change fillet of case for cnc
    [phalwol.3dm, phalwolCaseBridgedL.stl, phalwolCaseBridgedR.stl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]
2026-06-18 add plate stp file
    [phalwolPlateL.stp, phalwolPlateR.stp]
2026-06-18 Create external footprint license.txt
2026-06-19 add image check for case
2026-07-09 add caseFrame variation
    [phalwolCaseFrame.3mf, phalwolCaseFrameBridgedL.stl, phalwolCaseFrameBridgedR.stl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]
2026-07-09 update for weakest part
    [phalwolCaseFrame.3mf, phalwolCaseFrameBridgedL.stl, phalwolCaseFrameBridgedR.stl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]
2026-07-09 frame reinforcement for weakest part(again)
    [phalwolCaseFrame.3mf, phalwolCaseFrameBridgedL.stl, phalwolCaseFrameBridgedR.stl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]
2026-07-17 update CaseFrame to tentable and add more plate options
    [phalwolCaseBuffed.3mf, phalwolCaseFrame.3mf, phalwolCaseFrameBridgedL.stl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]
